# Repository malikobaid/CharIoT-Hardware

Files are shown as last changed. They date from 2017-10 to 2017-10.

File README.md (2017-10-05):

# CharIoT Custom Sensor PCB
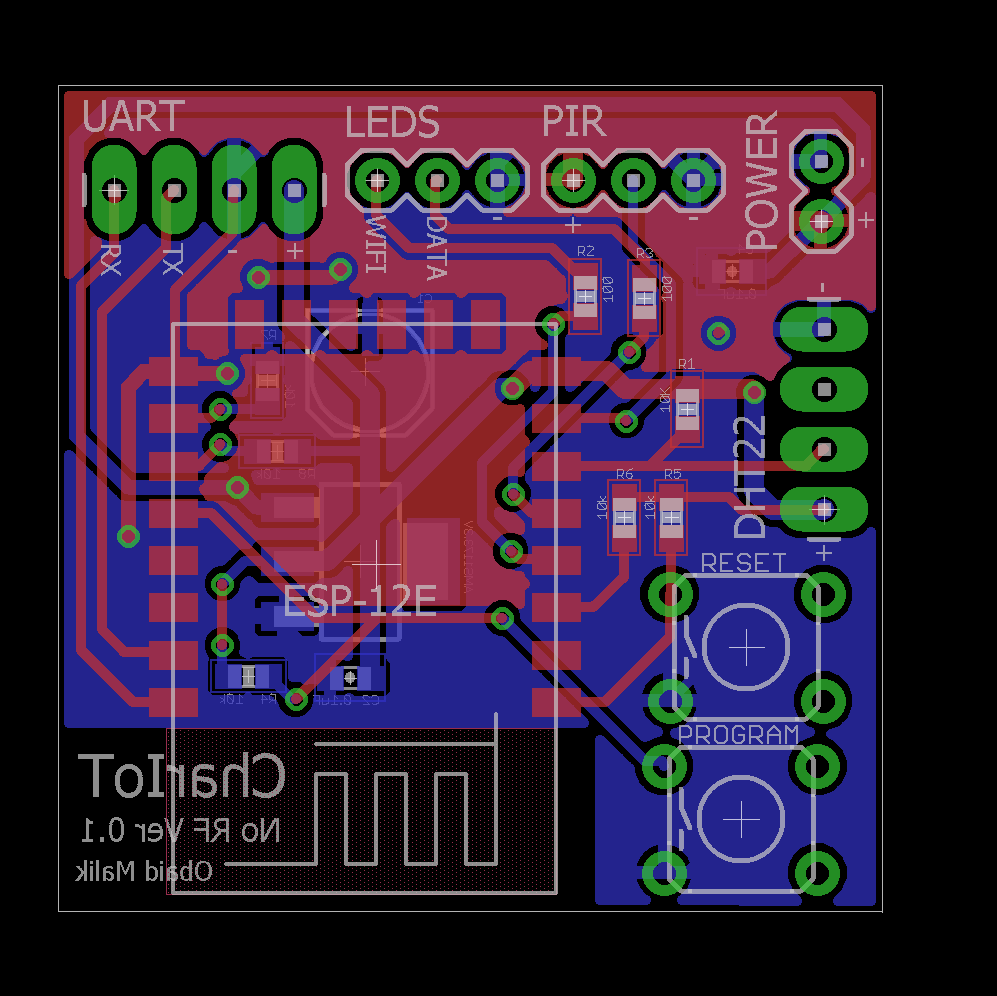
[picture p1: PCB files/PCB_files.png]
pcb


A DHT22 and ESP8266-12F based wifi temperature and humidity sensor that records and sends data to a custom influxdb server.

## Copyright and License

Copyright 2016-2017 CharIoT. <br> Released under the [MIT](https://github.com/BlackrockDigital/startbootstrap-landing-page/blob/gh-pages/LICENSE) license.

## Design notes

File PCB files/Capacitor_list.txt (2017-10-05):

C4     	1uf	0603  	SMD Multilayer Ceramic Capacitor	http://uk.farnell.com/murata/grm033r60j105mea2d/cap-mlcc-x5r-1uf-6-3v-0201/dp/2470448
C1     	100uf	FK 	SMD Aluminium Electrolytic Capacitor	http://uk.farnell.com/panasonic-electronic-components/eeefk0j101ur/cap-alu-elec-100uf-6-3v-smd/dp/1850085
C2     	0.1uf	0603	SMD Multilayer Ceramic Capacitor	http://uk.farnell.com/murata/grm033r60j104ke19d/cap-mlcc-x5r-100nf-6-3v-0201/dp/1775994
R1     	10K	0603	SMD Chip Resistor, Thick Film		http://uk.farnell.com/vishay/crcw060310k0fkea/res-thick-film-10k-1-0-1w-0603/dp/1469748
R2	100	0603	SMD Chip Resistor, Thick Film		http://uk.farnell.com/bourns/cr0603-jw-101glf/res-thick-film-100r-5-0-1w-0603/dp/2008349
R3	100	0603	SMD Chip Resistor, Thick Film		http://uk.farnell.com/bourns/cr0603-jw-101glf/res-thick-film-100r-5-0-1w-0603/dp/2008349
R4	10k	0603	SMD Chip Resistor, Thick Film		http://uk.farnell.com/vishay/crcw060310k0fkea/res-thick-film-10k-1-0-1w-0603/dp/1469748
R5	10k	0603	SMD Chip Resistor, Thick Film		http://uk.farnell.com/vishay/crcw060310k0fkea/res-thick-film-10k-1-0-1w-0603/dp/1469748
R6	10k	0603	SMD Chip Resistor, Thick Film		http://uk.farnell.com/vishay/crcw060310k0fkea/res-thick-film-10k-1-0-1w-0603/dp/1469748
R7	10k	0603	SMD Chip Resistor, Thick Film		http://uk.farnell.com/vishay/crcw060310k0fkea/res-thick-film-10k-1-0-1w-0603/dp/1469748
R8	10k	0603	SMD Chip Resistor, Thick Film		http://uk.farnell.com/vishay/crcw060310k0fkea/res-thick-film-10k-1-0-1w-0603/dp/1469748

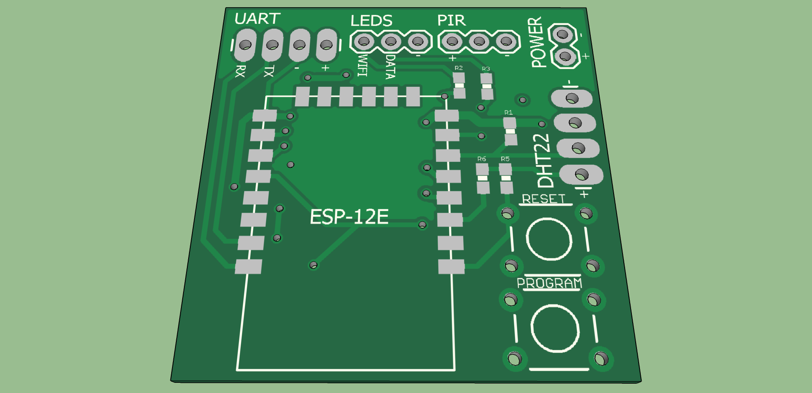
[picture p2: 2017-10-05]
PCB files/PCB_3D_TOP.png

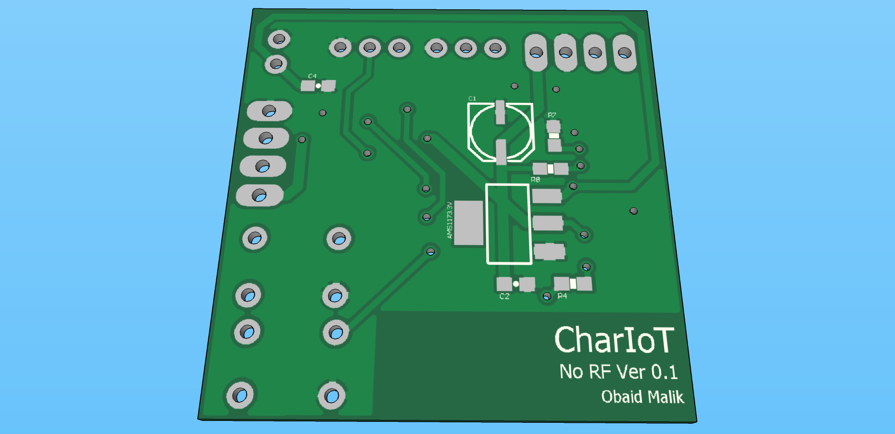
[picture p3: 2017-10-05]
PCB files/PCB_3D_BOT.png

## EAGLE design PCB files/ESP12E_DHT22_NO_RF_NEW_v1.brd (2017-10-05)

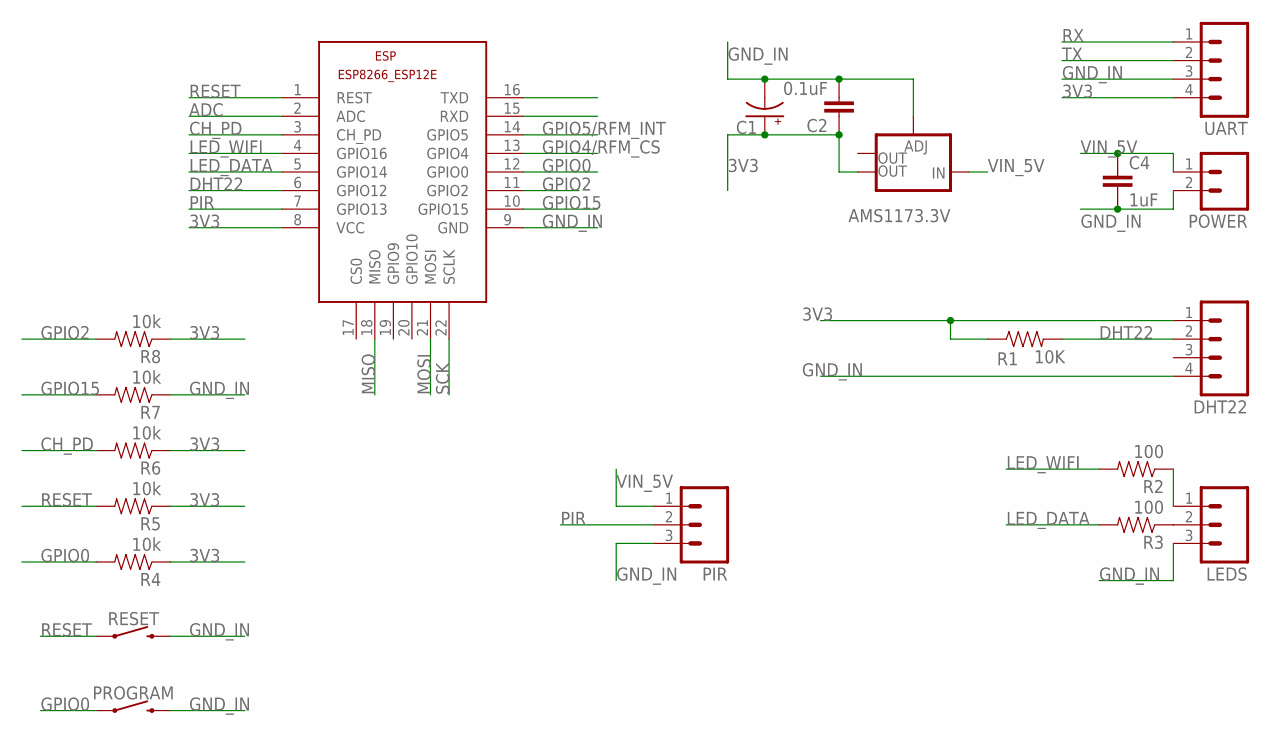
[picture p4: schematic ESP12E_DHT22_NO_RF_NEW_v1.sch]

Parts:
AMS1173.3V: V_REG_LM1117SOT223; SOT223
C1: CAP_POLC; PANASONIC_C
C2: 0.1uF; 0603-CAP
C4: 1uF; 0603-CAP
DHT22: M04LONGPADS; 1X04_LONGPADS
ESP: ESP8266-12EESP8266-ESP12E; ESP8266-ESP12E
LEDS: M03PTH; 1X03
PIR: M03PTH; 1X03
POWER: M02PTH; 1X02
PROGRAM: MOMENTARY-SWITCH-SPST-PTH-6.0MM-KIT; TACTILE_SWITCH_PTH_6.0MM_KIT
R1: 10K; 0603-RES
R2, R3: 100; 0603-RES
R4, R5, R6, R7, R8: 10k; 0603-RES
RESET: MOMENTARY-SWITCH-SPST-PTH-6.0MM-KIT; TACTILE_SWITCH_PTH_6.0MM_KIT
UART: M04LONGPADS; 1X04_LONGPADS

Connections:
3V3: AMS1173.3V.2 (OUT), C1.+, C2.1, DHT22.1, ESP.8 (VCC), R1.1, R4.1, R5.1, R6.1, R8.1, UART.4
ADC: ESP.2 (ADC)
CH_PD: ESP.3 (CH_PD), R6.2
DHT22: DHT22.2, ESP.6 (GPIO12), R1.2
GND_IN: AMS1173.3V.1 (ADJ), C1.-, C2.2, C4.2, DHT22.4, ESP.9 (GND), LEDS.3, PIR.3, POWER.2, PROGRAM.3 (2), R7.1, RESET.3 (2), UART.3
GPIO0: ESP.12 (GPIO0), PROGRAM.1, R4.2
GPIO2: ESP.11 (GPIO2), R8.2
GPIO4/RFM_CS: ESP.13 (GPIO4)
GPIO5/RFM_INT: ESP.14 (GPIO5)
GPIO15: ESP.10 (GPIO15), R7.2
LED_DATA: ESP.5 (GPIO14), R3.2
LED_WIFI: ESP.4 (GPIO16), R2.2
MISO: ESP.18 (MISO)
MOSI: ESP.21 (MOSI)
unnamed: LEDS.2, R3.1
unnamed: LEDS.1, R2.1
PIR: ESP.7 (GPIO13), PIR.2
RESET: ESP.1 (REST), R5.2, RESET.1
RX: ESP.16 (TXD), UART.1
SCK: ESP.22 (SCLK)
TX: ESP.15 (RXD), UART.2
VIN_5V: AMS1173.3V.3 (IN), C4.1, PIR.1, POWER.1

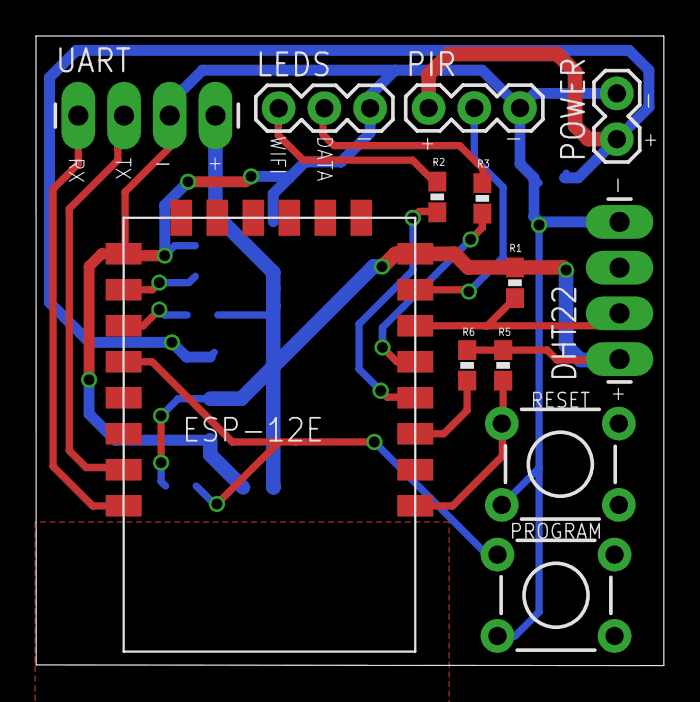
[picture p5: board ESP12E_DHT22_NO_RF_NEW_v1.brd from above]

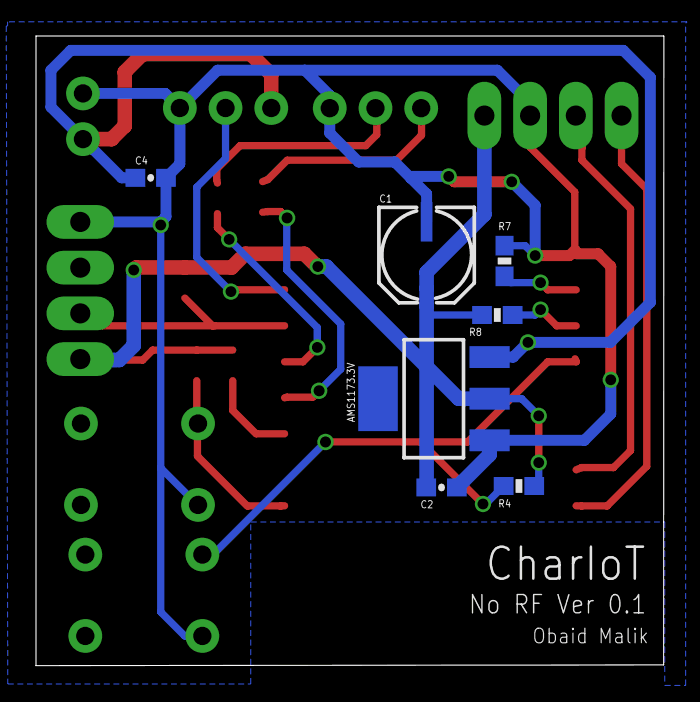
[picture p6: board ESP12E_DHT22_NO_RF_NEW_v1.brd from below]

Board: 2 copper layers, 34.9 x 35.0 mm, 20 parts (7 on the bottom side), 16 nets.

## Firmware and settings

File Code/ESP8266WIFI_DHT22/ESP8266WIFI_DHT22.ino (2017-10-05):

// Send DHT22 and Pir data to influx db hoseted on <<Server_IP>> using an ESP8266
// July 25 2017
// Author: Obaid Malik

#include <DHT.h>
#include <DHT_U.h>
#include <ESP8266WiFi.h>

String strLocation = "Lounge"; const int SensorID = 1; const int TC = 0.0; const int HC = 0.0; //Sensor 1

////// Testing
const char* ssid = "SSID1";
const char* password = "PASS1";
const char* ssid2 = "SSID2";
const char* password2 = "PASS2";

const float timebwreadings = 0.9L;
const char* server = "<<Server_IP>>";

// New sensors
#define DHTPIN 12 // what pin we’re connected to
#define PIRPIN 13 // what pin we’re connected to
#define DHTTYPE DHT22
#define WIFIOKPIN 16
#define SENDOKPIN 14

DHT dht(DHTPIN, DHTTYPE);
WiFiClient client;

void init_components() {
  Serial.begin(9600);
  delay(30);
  Serial.println();
  Serial.print("Initilizing components for Sensor: ");
  Serial.print(SensorID);
  Serial.println(" .....");
  pinMode(WIFIOKPIN, OUTPUT);
  pinMode(SENDOKPIN, OUTPUT);
  pinMode(PIRPIN, INPUT);

  //Test LEDS
  digitalWrite(WIFIOKPIN, HIGH);    // turn the LED off by making the voltage LOW
  digitalWrite(SENDOKPIN, HIGH);    // turn the LED off by making the voltage LOW
  delay(400);
  digitalWrite(WIFIOKPIN, LOW);     // turn the LED off by making the voltage LOW
  digitalWrite(SENDOKPIN, LOW);     // turn the LED off by making the voltage LOW
  delay(30);
  dht.begin();
}

void setup() {
  init_components();
  connectToAvailableWifi();
  Serial.println("Waiting for PIR sensor Initilization:");
  delay(55000);                     // The Pir Sensor need 60 sec to initilize we wait 55 sec the remaining will be covered doing wifi setup
  Serial.println("PIR sensor Initilizied:");
}


int firstReading = 1;
void loop() {

  digitalWrite(SENDOKPIN, LOW);

  if (firstReading == 0) {
    digitalWrite(WIFIOKPIN, LOW);
  }

  bool isConnected = connectToAvailableWifi();
  if (isConnected) {
    float h = dht.readHumidity();
    float t = dht.readTemperature();
    h = h + HC;
    t = t + TC;
    float tF = ((t * 9) / 5) + 32;
    float dP = (dewPointFast(t, h));
    float hi = heatIndex(tF, h);
    int presence = (digitalRead(PIRPIN) == HIGH) ? 1 : 0; // check if the sensor is HIGH, For some reason assigning direct value from digitread to presence variable doesnt seem to work. check Later?
    delay(100);

    if (client.connect(server, 8086)) { 
      String postStr = "SensorDataPIR,SensorID=" + String(SensorID) + " Temperature=" + String(t) + ",Humidity=" + String(h) + ",Dewpoint=" + String(dP) + ",HeatIndex=" + String(hi) + ",Presence=" + String(presence);
      Serial.println(postStr);
      client.print("POST /write?db=chariot HTTP/1.1\n");
      client.print("Host: <<Server_IP>>\n");
      client.print("Connection: close\n");
      client.print("Content-Type: application/x-www-form-urlencoded\n");
      client.print("Content-Length: ");
      client.print(postStr.length());
      client.print("\n\n");
      client.print(postStr);

      delay(3000);
      while (client.available()) {
        String line = client.readStringUntil('\r');
        Serial.println(line);
        if (line.indexOf("204 No Content") > 0) {
          Serial.println("Post to Server successfull");
          if (firstReading) {
            digitalWrite(SENDOKPIN, HIGH); //Only light up led if first reading
            firstReading = 0;
          }
        }
      }
    }
    client.stop();
  } else {
    Serial.println("No suitable wifi available");
    digitalWrite(SENDOKPIN, LOW);
    digitalWrite(WIFIOKPIN, LOW);
  }
  Serial.println("yaaaawn .... going to sleep for 1 min");
  delay(60000 * timebwreadings);
}

bool connectToAvailableWifi() {
  bool connectionOk = true;
  if (WiFi.status() != WL_CONNECTED) {
    connectionOk = waitForWifiConnect(40, ssid, password);
    if (connectionOk == false) {
      connectionOk = waitForWifiConnect(40, ssid2, password2);
    }

    if (connectionOk && firstReading) { //Activate LED if first reading
      digitalWrite(WIFIOKPIN, HIGH);
    }
  } else {
    if (firstReading) {
      digitalWrite(WIFIOKPIN, HIGH);
    }
    Serial.println("WiFi connected");
  }
  return connectionOk;
}
bool waitForWifiConnect(int retrys, const char* sid, const char* pass) {
  WiFi.begin(sid, pass);
  Serial.println();
  Serial.print("Connecting to ");
  Serial.println(sid);
  delay(1000);
  bool connectionOk = false;
  for (int i = 1; i < retrys; i++) {
    if (WiFi.status() != WL_CONNECTED) {
      digitalWrite(WIFIOKPIN, HIGH);
      delay(200);
      Serial.print(".");
      digitalWrite(WIFIOKPIN, LOW);
      delay(200);
      connectionOk = false;
    } else {
      //digitalWrite(WIFIOKPIN, HIGH); //Let the calling function handle the LED output
      Serial.println("WiFi connected");
      i = retrys + 1;
      connectionOk = true;
    }
  }
  Serial.println("");
  return connectionOk;
}

// delta max = 0.6544 wrt dewPoint()
// 6.9 x faster than dewPoint()
// reference: http://en.wikipedia.org/wiki/Dew_point
double dewPointFast(double celsius, double humidity)
{
  double a = 17.271;
  double b = 237.7;
  double temp = (a * celsius) / (b + celsius) + log(humidity * 0.01);
  double Td = (b * temp) / (a - temp);
  return Td;
}

double heatIndex(double tempF, double humidity)
{
  double c1 = -42.38, c2 = 2.049, c3 = 10.14, c4 = -0.2248, c5 = -6.838e-3, c6 = -5.482e-2, c7 = 1.228e-3, c8 = 8.528e-4, c9 = -1.99e-6  ;
  double T = tempF;
  double R = humidity;

  double A = (( c5 * T) + c2) * T + c1;
  double B = ((c7 * T) + c4) * T + c3;
  double C = ((c9 * T) + c8) * T + c6;

  double rv = (C * R + B) * R + A;
  return rv;
}

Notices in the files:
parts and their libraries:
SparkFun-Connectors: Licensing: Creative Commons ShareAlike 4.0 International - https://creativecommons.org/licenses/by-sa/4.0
